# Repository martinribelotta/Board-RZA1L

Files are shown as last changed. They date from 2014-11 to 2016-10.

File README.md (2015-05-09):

RZ/A1L Board
============

Cortex-A9 board for Renesas RZ CPU using KiCAD

Hardware
--------

 - **CPU**: RZ/A1L 208LQFP
 - **RAM**: 32/64M sdram
 - **Flash**: 16/32M QSPI FLASH
 - **VGA**: 24bpp@\<TBD\>Hz
 - **USB**: 1 Host & 1 Dev
 - **GPIO**: 30 GPIO (+6 LED +2 Button) Muxed with:

Block Diagram
-------------

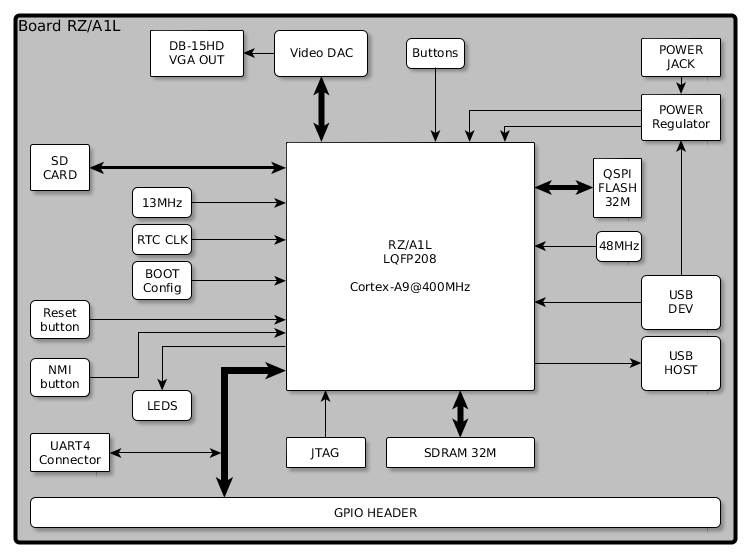
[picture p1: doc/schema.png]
Block Diagram


Schematic
---------

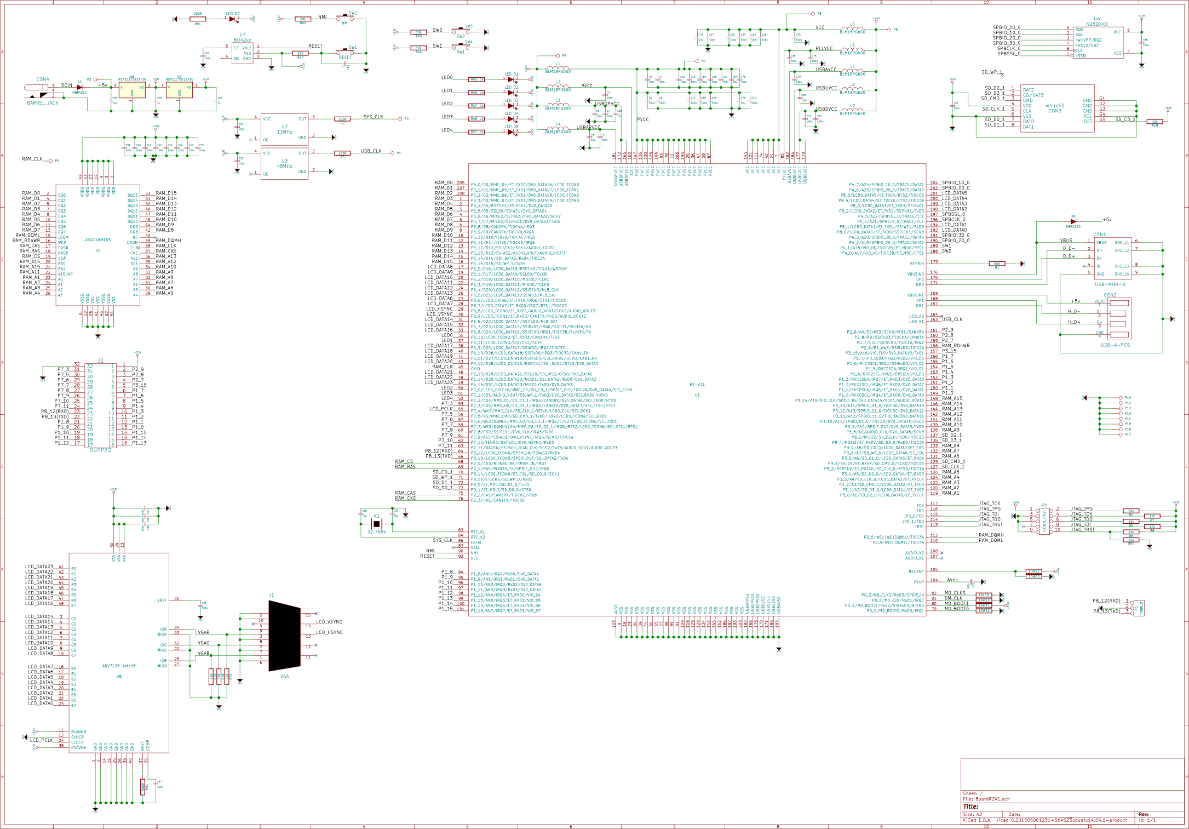
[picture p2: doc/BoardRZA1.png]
Schematic


Preview
-------

Top view

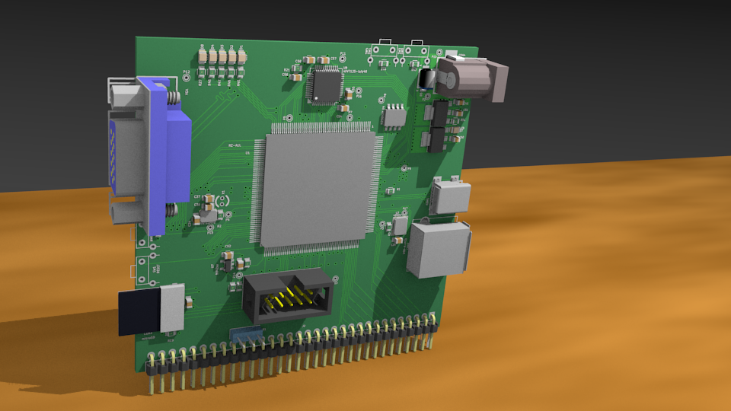
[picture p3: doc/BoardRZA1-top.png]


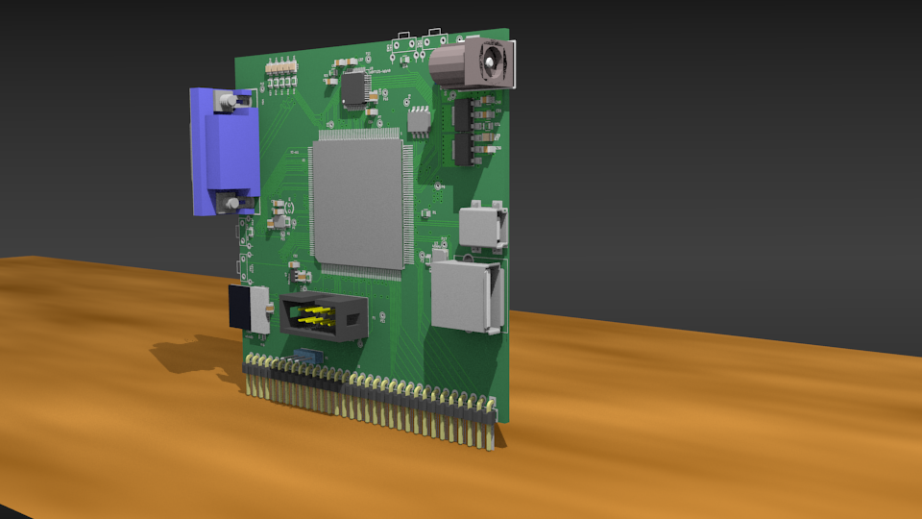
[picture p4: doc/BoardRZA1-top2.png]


Bottom view

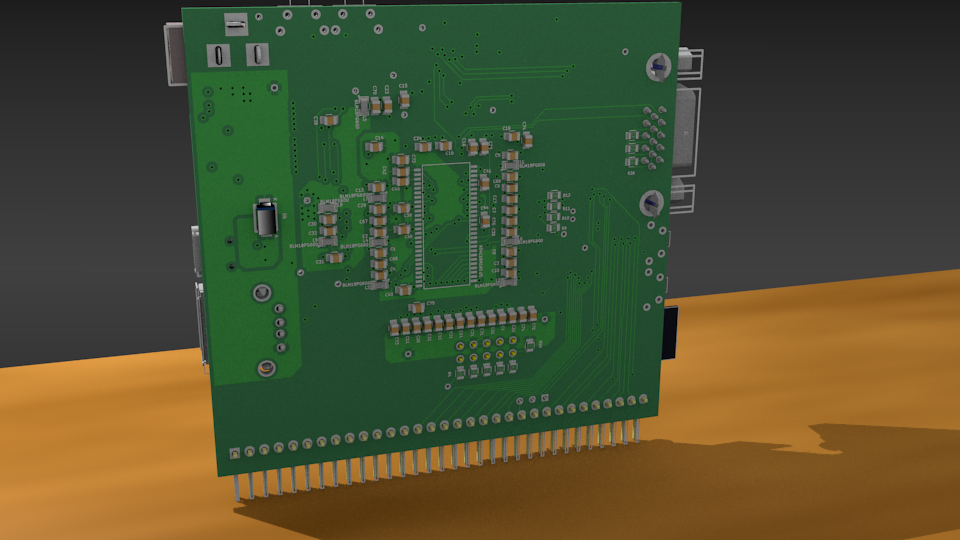
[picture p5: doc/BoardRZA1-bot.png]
Bottom


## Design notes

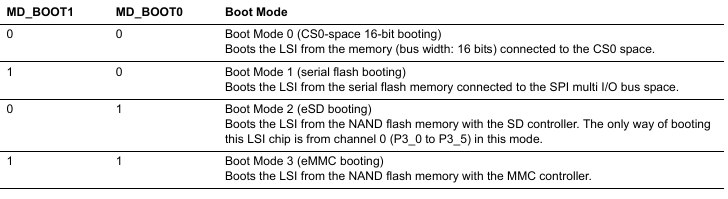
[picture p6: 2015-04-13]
doc/boot-modes-a1l.png

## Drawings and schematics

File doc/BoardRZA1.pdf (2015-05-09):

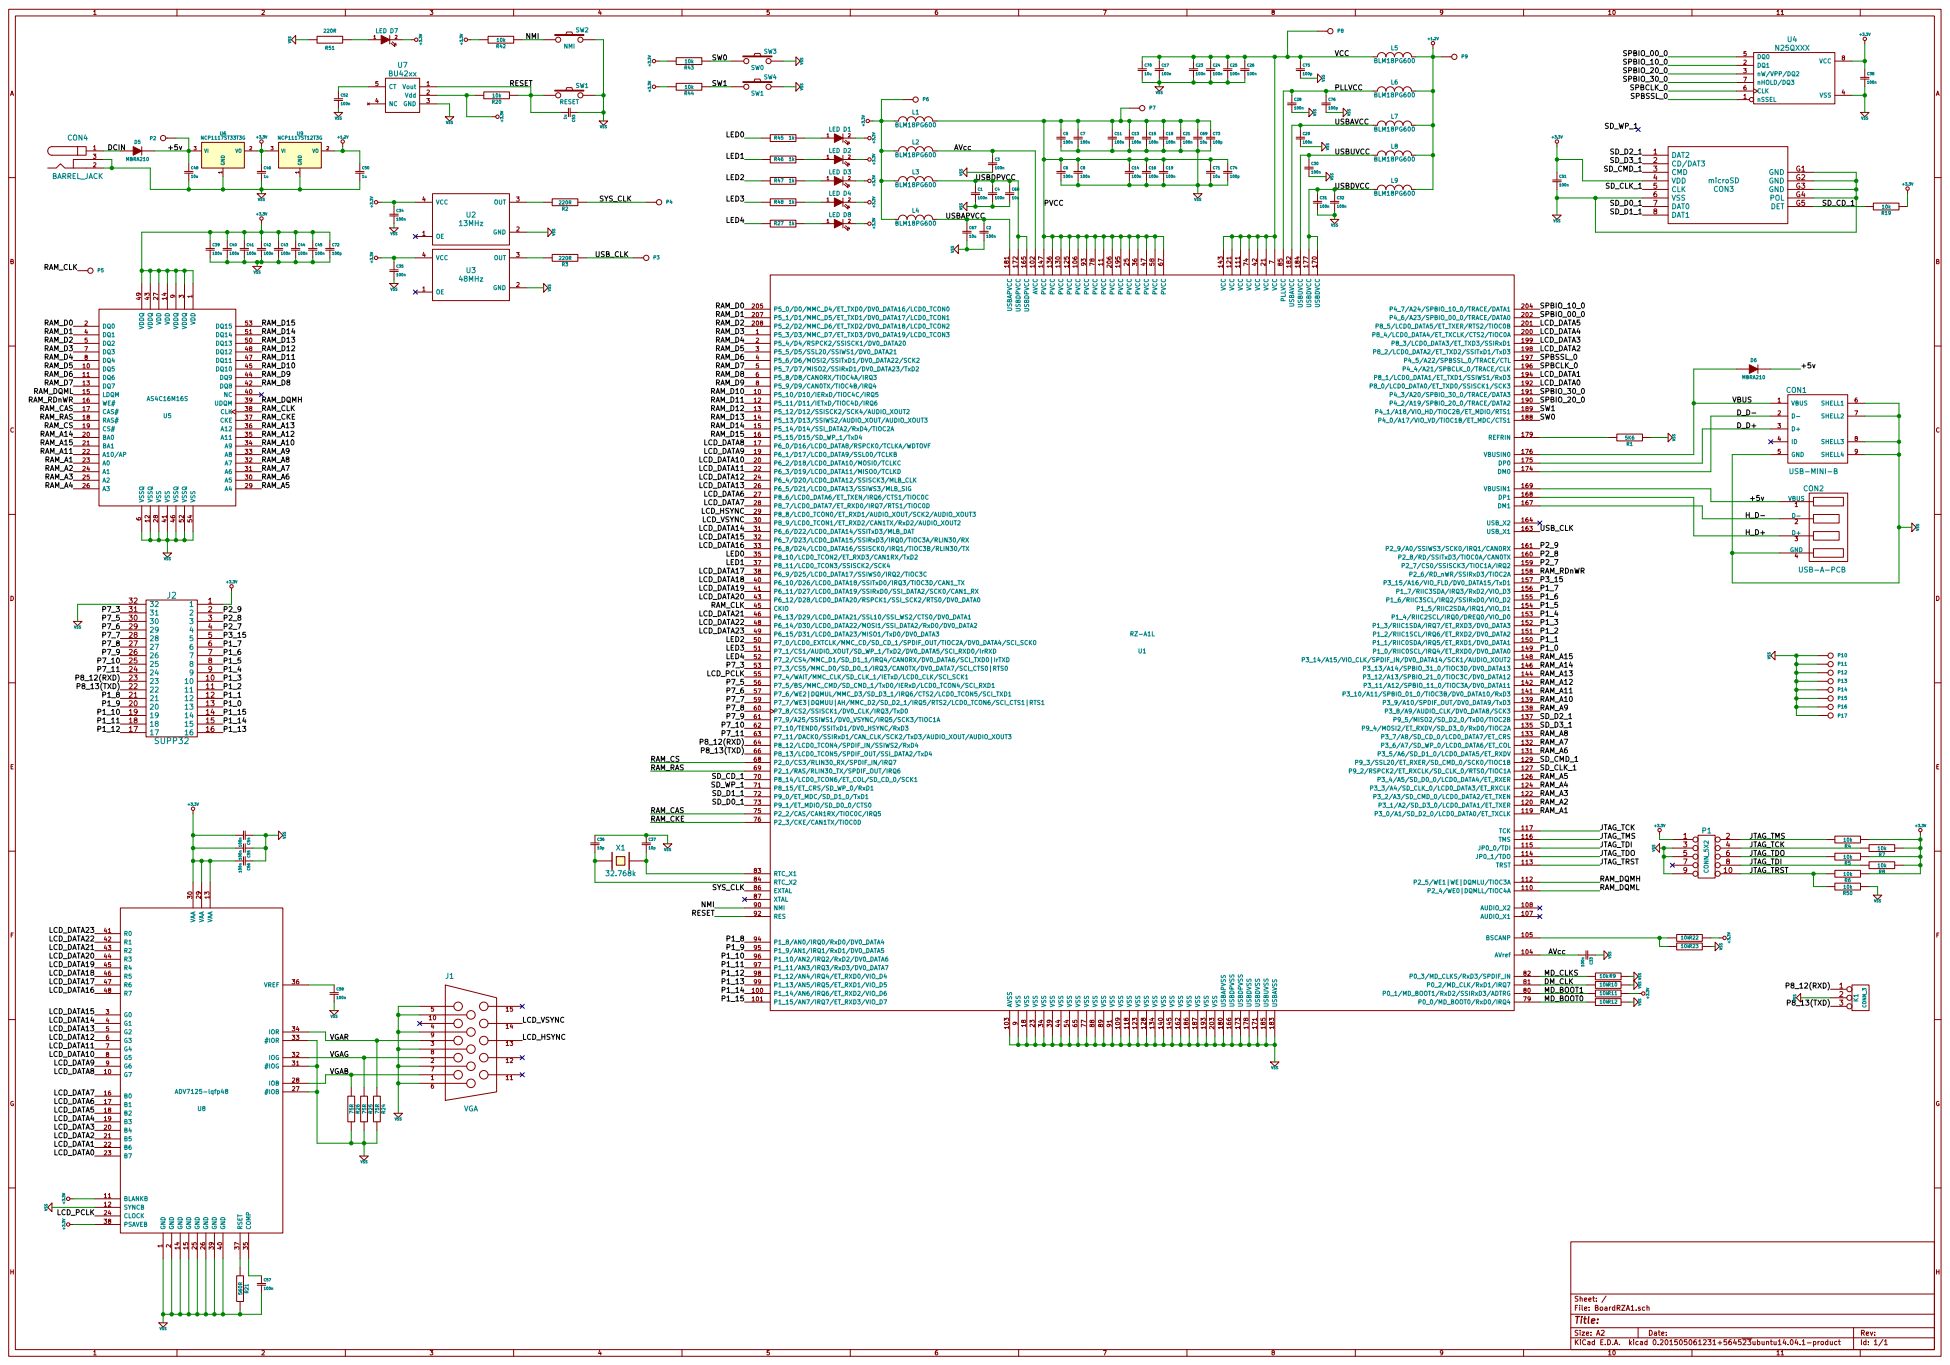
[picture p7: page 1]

9 DQ5 10 BA0 20 A5 30 NC 40 DQ13 50 DQ6 11 BA1 21 A6 31 VSS 41 DQ14 51 VSSQ 12 A10/AP 22 A7 32 DQ8 42 VSSQ 52 DQ7 13 A0 23 A8 33 VDDQ 43 DQ15 VDD 53 14 A1 24 A9 34 DQ9 44 VSS 54

Id: 1/1 Title: File: BoardRZA1.sch Sheet: /

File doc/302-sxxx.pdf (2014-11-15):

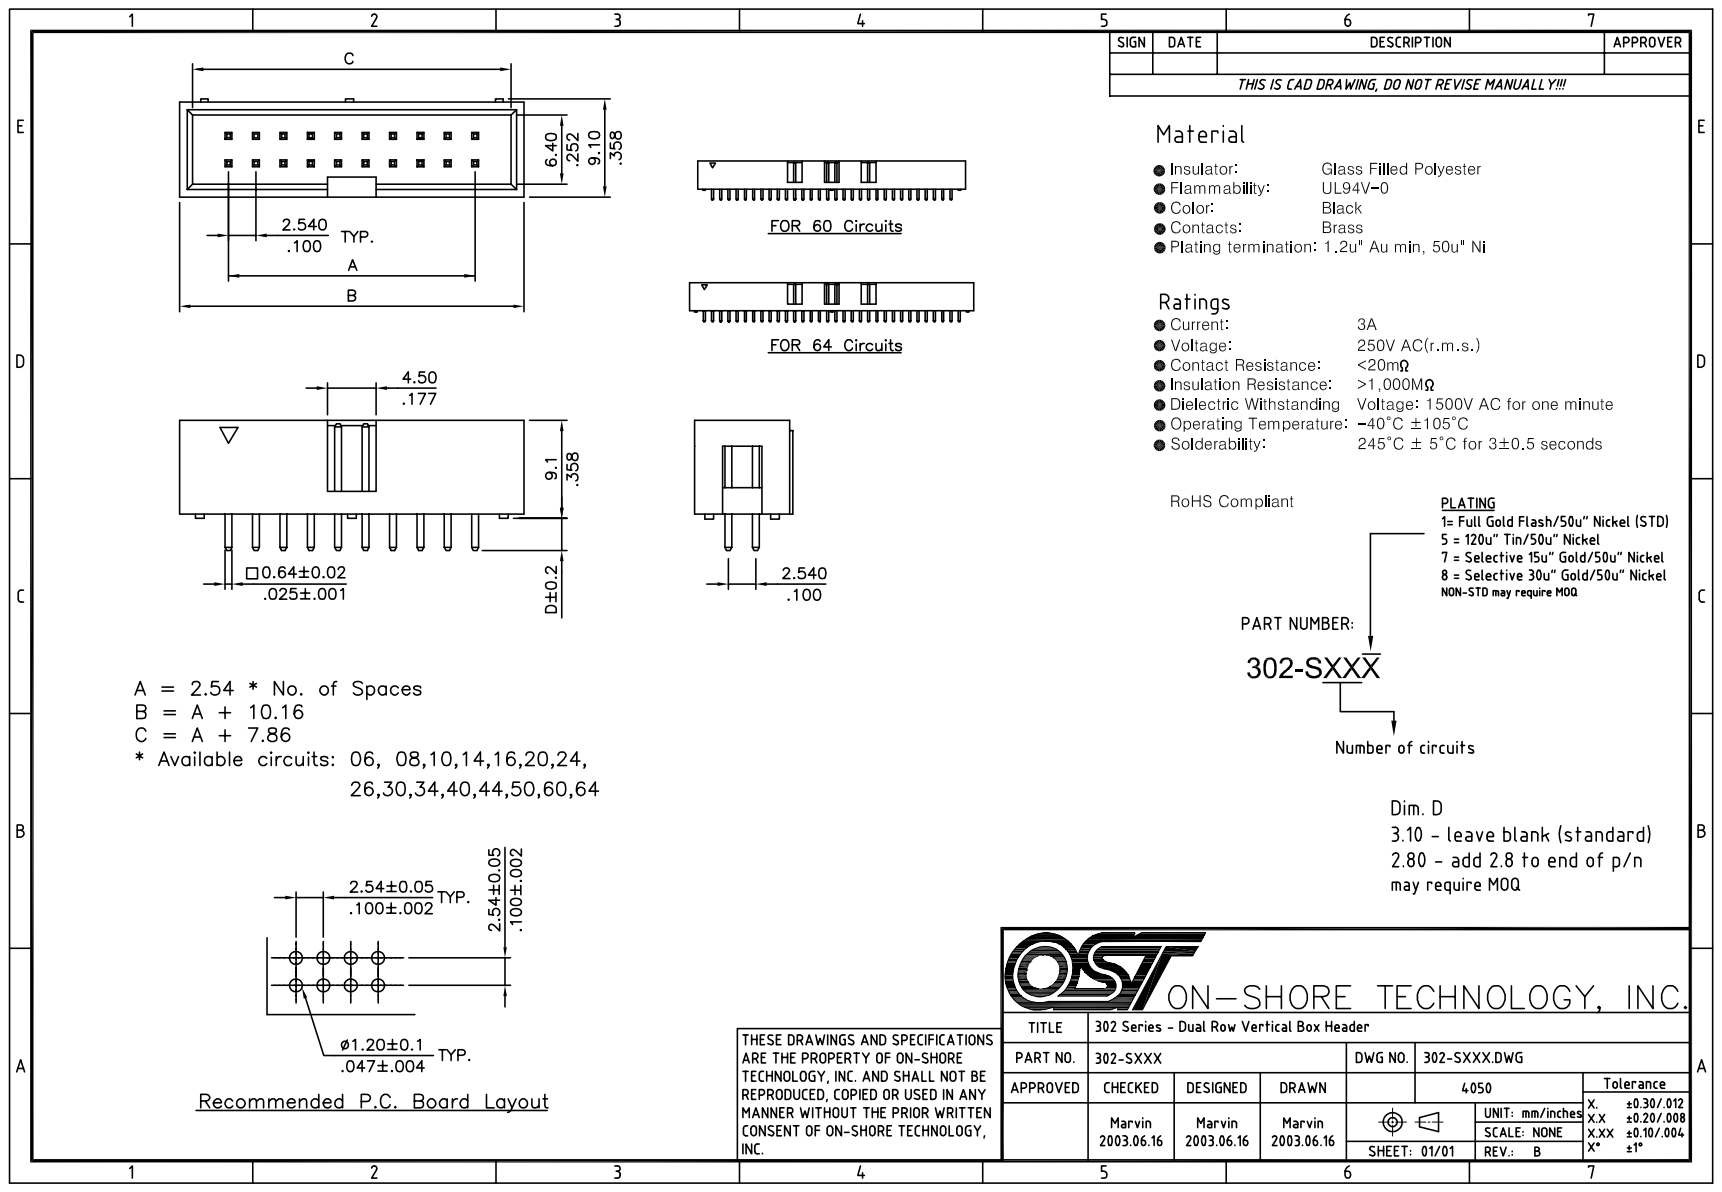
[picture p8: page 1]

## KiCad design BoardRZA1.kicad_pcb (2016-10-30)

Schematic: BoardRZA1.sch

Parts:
C1, C2, C3, C4, C5, C6, C7, C8, C11, C13, C14, C15, C16, C17, C18, C19, C21, C23, C24, C25, C26, C28, C29, C30, C31, C32, C33, C34, C35, C38, C39, C40, C41, C42, C43, C44, C45, C51, C52: 100n; C_0805
C36, C37: 10p; C_0805
C46, C50, C53: 1u; C_0805
C48, C67, C68, C69, C70, C71: 10u; C_0805
C72, C73, C74, C75, C76: 100p; C_0805
CON1: USB-MINI-B; USB_MINI_B
CON2: USB-A-PCB; USB_A_Vertical
CON3: microSD
D1, D2, D3, D4, D7, D8: LED; LED-0805
L1, L2, L3, L4, L5, L6, L7, L8, L9: BLM18PG600; SM0805
P1: CONN_02X04; Pin_Header_Straight_2x04
P2, P3, P4, P5, P6, P7, P8, P9, P10, P11, P12, P13, P14, P15, P16, P17: CONN_1; PINTST
P18, P19: CONN_01X40; Pin_Header_Straight_2x20
R1: 5K6; R_0805
R2, R3, R51: 220R; R_0805
R4, R5, R6, R7, R8, R9, R10, R11, R12, R19, R20, R22, R23, R42, R43, R44, R50: 10k; R_0805
R27, R45, R46, R47, R48: 1k; R_0805
SW1: RESET; RigthAnglePush
SW2: NMI; RigthAnglePush
SW3: SW0; RigthAnglePush
SW4: SW1; RigthAnglePush
U1: RZ-A1L; PQFP208
U2: 13MHz; OSC_2x2p5
U3: 48MHz; OSC_4PIN
U4: N25QXXX; SOP2-8
U5: AS4C16M16S; TSOP_II_54
U6: NCP1117ST33T3G; sot223
U7: BU42xx; SSOP-5
U9: NCP1117ST12T3G; sot223
X1: 32.768k; Crystal_Round_Vertical_3mm

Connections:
+1.2V: C50.1, L5.2, L6.2, L7.2, L8.2, L9.2, P9.1, U9.2 (VO)
+3.3V: C34.1, C35.1, C38.1, C39.1, C40.1, C41.1, C42.1, C43.1, C44.1, C45.1, C46.1, C51.1, C72.1, CON3.4 (VDD), D1.2 (K), D2.2 (K), D3.2 (K), D4.2 (K), D7.2 (K), D8.2 (K), L1.1, L2.1, L3.1, L4.1, P6.1, P18.3, P18.4, P18.37, P18.38, P19.3, P19.4, P19.37, P19.38, R4.1, R5.1, R6.1, R7.1, R8.1, R11.1, R19.1, R20.2, R22.1, R42.2, R43.2, R44.2, U2.4 (VCC), U3.4 (VCC), U4.8 (VCC), U5.1 (VDD), U5.3 (VDDQ), U5.9 (VDDQ), U5.14 (VDD), U5.27 (VDD), U5.43 (VDDQ), U5.49 (VDDQ), U6.2 (VO), U7.2 (Vdd), U9.3 (VI)
/+5v: C48.1, CON1.1 (VBUS), CON2.1 (VBUS), P2.1, U1.169 (VBUSIN1), U1.176 (VBUSIN0), U6.3 (VI)
/AVcc: C3.1, C33.2, L2.2, U1.102 (AVCC), U1.104 (AVref)
/DM_CLK: R10.2, U1.81 (P0_2/MD_CLK/RxD1/IRQ7)
/D_D+: CON1.3 (D+), U1.175 (DP0)
/D_D-: CON1.2 (D-), U1.174 (DM0)
/H_D+: CON2.3 (D+), U1.168 (DP1)
/H_D-: CON2.2 (D-), U1.167 (DM1)
/JTAG_TCK: P1.2, R7.2, U1.117 (TCK)
/JTAG_TDI: P1.6, R8.2, U1.115 (JP0_0/TDI)
/JTAG_TDO: P1.4, R5.2, U1.114 (JP0_1/TDO)
/JTAG_TMS: P1.1, R4.2, U1.116 (TMS)
/JTAG_TRST: P1.8, R6.2, R50.2, U1.113 (TRST)
/LCD_DATA0: P18.19, U1.192 (P8_0/LCD0_DATA0/ET_TXD0/SSISCK1/SCK3)
/LCD_DATA1: P18.20, U1.194 (P8_1/LCD0_DATA1/ET_TXD1/SSIWS1/RxD3)
/LCD_DATA2: P18.21, U1.198 (P8_2/LCD0_DATA2/ET_TXD2/SSITxD1/TxD3)
/LCD_DATA3: P18.22, U1.199 (P8_3/LCD0_DATA3/ET_TXD3/SSIRxD1)
/LCD_DATA4: P18.23, U1.200 (P8_4/LCD0_DATA4/ET_TXCLK/CTS2/TIOC0A)
/LCD_DATA5: P18.24, U1.201 (P8_5/LCD0_DATA5/ET_TXER/RTS2/TIOC0B)
/LCD_DATA6: P18.31, U1.27 (P8_6/LCD0_DATA6/ET_TXEN/IRQ6/CTS1/TIOC0C)
/LCD_DATA7: P18.32, U1.28 (P8_7/LCD0_DATA7/ET_RXD0/IRQ7/RTS1/TIOC0D)
/LCD_DATA8: P18.25, U1.17 (P6_0/D16/LCD0_DATA8/RSPCK0/TCLKA/WDTOVF)
/LCD_DATA9: P18.26, U1.19 (P6_1/D17/LCD0_DATA9/SSL00/TCLKB)
/LCD_DATA10: P18.27, U1.20 (P6_2/D18/LCD0_DATA10/MOSI0/TCLKC)
/LCD_DATA11: P18.28, U1.22 (P6_3/D19/LCD0_DATA11/MISO0/TCLKD)
/LCD_DATA12: P18.29, U1.24 (P6_4/D20/LCD0_DATA12/SSISCK3/MLB_CLK)
/LCD_DATA13: P18.30, U1.26 (P6_5/D21/LCD0_DATA13/SSIWS3/MLB_SIG)
/LCD_DATA14: P18.35, U1.31 (P6_6/D22/LCD0_DATA14/SSITxD3/MLB_DAT)
/LCD_DATA15: P18.36, U1.32 (P6_7/D23/LCD0_DATA15/SSIRxD3/IRQ0/TIOC3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)
/LCD_DATA16: P19.5, U1.33 (P6_8/D24/LCD0_DATA16/SSISCK0/IRQ1/TIOC3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)
/LCD_DATA17: P19.8, U1.38 (P6_9/D25/LCD0_DATA17/SSIWS0/IRQ2/TIOC3C)
/LCD_DATA18: P19.9, U1.40 (P6_10/D26/LCD0_DATA18/SSITxD0/IRQ3/TIOC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)
/LCD_DATA19: P19.10, U1.41 (P6_11/D27/LCD0_DATA19/SSIRxD0/SSI_DATA2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)
/LCD_DATA20: P19.11, U1.43 (P6_12/D28/LCD0_DATA20/RSPCK1/SSI_SCK2/R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)
/LCD_DATA21: P19.12, U1.46 (P6_13/D29/LCD0_DATA21/SSL10/SSI_WS2/CTS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)
/LCD_DATA22: P19.13, U1.48 (P6_14/D30/LCD0_DATA22/MOSI1/SSI_DATA2/R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)
/LCD_DATA23: P19.14, U1.49 (P6_15/D31/LCD0_DATA23/MISO1/TxD0/DV0_DA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)
/LCD_HSYNC: P18.33, U1.29 (P8_8/LCD0_TCON0/ET_RXD1/AUDIO_XOUT/SCK2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)
/LCD_PCLK: P19.19, U1.55 (P7_4/WAIT/MMC_CLK/SD_CLK_1/IETxD/LCD0_C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)
/LCD_VSYNC: P18.34, U1.30 (P8_9/LCD0_TCON1/ET_RXD2/CAN1TX/RxD2/AUD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)
/LED0: P19.7, R45.1, U1.35 (P8_10/LCD0_TCON2/ET_RXD3/CAN1RX/TxD2)
/LED1: P19.6, R46.1, U1.37 (P8_11/LCD0_TCON3/SSISCK2/SCK4)
/LED2: P19.15, R47.1, U1.50 (P7_0/LCD0_EXTCLK/MMC_CD/SD_CD_1/SPDIF_O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)
/LED3: P19.16, R48.1, U1.51 (P7_1/CS1/AUDIO_XOUT/SD_WP_1/TxD2/DV0_DA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)
/LED4: P19.17, R27.1, U1.52 (P7_2/CS4/MMC_D1/SD_D1_1/IRQ4/CAN0RX/DV0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)
/MD_BOOT0: R12.2, U1.79 (P0_0/MD_BOOT0/RxD0/IRQ4)
/MD_BOOT1: R11.2, U1.80 (P0_1/MD_BOOT1/RxD2/SSIRxD3/ADTRG)
/MD_CLKS: R9.2, U1.82 (P0_3/MD_CLKS/RxD3/SPDIF_IN)
/NMI: P19.27, R42.1, SW2.1, U1.90 (NMI)
/P1_0: P18.5, U1.149 (P1_0/RIIC0SCL/IRQ4/ET_RXD0/DV0_DATA0)
/P1_1: P18.6, U1.150 (P1_1/RIIC0SDA/IRQ5/ET_RXD1/DV0_DATA1)
/P1_2: P18.7, U1.151 (P1_2/RIIC1SCL/IRQ6/ET_RXD2/DV0_DATA2)
/P1_3: P18.8, U1.152 (P1_3/RIIC1SDA/IRQ7/ET_RXD3/DV0_DATA3)
/P1_4: P18.9, U1.153 (P1_4/RIIC2SCL/IRQ0/DREQ0/VIO_D0)
/P1_5: P18.10, U1.154 (P1_5/RIIC2SDA/IRQ1/VIO_D1)
/P1_6: P18.11, U1.155 (P1_6/RIIC3SCL/IRQ2/SSIRxD0/VIO_D2)
/P1_7: P18.12, U1.156 (P1_7/RIIC3SDA/IRQ3/RxD2/VIO_D3)
/P1_8: P19.29, U1.94 (P1_8/AN0/IRQ0/RxD0/DV0_DATA4)
/P1_9: P19.30, U1.95 (P1_9/AN1/IRQ1/RxD1/DV0_DATA5)
/P1_10: P19.31, U1.96 (P1_10/AN2/IRQ2/RxD2/DV0_DATA6)
/P1_11: P19.32, U1.97 (P1_11/AN3/IRQ3/RxD3/DV0_DATA7)
/P1_12: P19.33, U1.98 (P1_12/AN4/IRQ4/ET_RXD0/VIO_D4)
/P1_13: P19.34, U1.99 (P1_13/AN5/IRQ5/ET_RXD1/VIO_D5)
/P1_14: P19.35, U1.100 (P1_14/AN6/IRQ6/ET_RXD2/VIO_D6)
/P1_15: P19.36, U1.101 (P1_15/AN7/IRQ7/ET_RXD3/VIO_D7)
/P2_7: P18.14, U1.159 (P2_7/CS0/SSISCK3/TIOC1A/IRQ2)
/P2_8: P18.15, U1.160 (P2_8/RD/SSITxD3/TIOC0A/CAN0TX)
/P2_9: P18.16, U1.161 (P2_9/A0/SSIWS3/SCK0/IRQ1/CAN0RX)
/P3_15: P18.13, U1.157 (P3_15/A16/VIO_FLD/DV0_DATA15/TxD1)
/P7_3: P19.18, U1.53 (P7_3/CS5/MMC_D0/SD_D0_1/IRQ3/CAN0TX/DV0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)
/P7_5: P19.20, U1.56 (P7_5/BS/MMC_CMD/SD_CMD_1/TxD0/IERxD/LCD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)
/P7_6: P19.21, U1.57 (P7_6/WE2|DQMUL/MMC_D3/SD_D3_1/IRQ6/CTS2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)
/P7_7: P19.22, U1.59 (P7_7/WE3|DQMUU|AH/MMC_D2/SD_D2_1/IRQ5/R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)
/P7_8: P19.23, U1.60 (P7_8/CS2/SSISCK1/DV0_CLK/IRQ3/TxD0)
/P7_9: P19.24, U1.61 (P7_9/A25/SSIWS1/DV0_VSYNC/IRQ5/SCK3/TIO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)
/P7_10: P19.25, U1.62 (P7_10/TEND0/SSITxD1/DV0_HSYNC/RxD3)
/P7_11: P19.26, U1.63 (P7_11/DACK0/SSIRxD1/CAN_CLK/SCK2/TxD3/A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)
/P8_12(RXD): P1.3, U1.64 (P8_12/LCD0_TCON4/SPDIF_IN/SSIWS2/RxD4)
/P8_13(TXD): P1.5, U1.66 (P8_13/LCD0_TCON5/SPDIF_OUT/SSI_DATA2/Tx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)
/PLLVCC: C28.1, C76.1, L6.1, U1.85 (PLLVCC)
/PVCC: C5.1, C6.1, C7.1, C8.1, C11.1, C13.1, C14.1, C15.1, C16.1, C18.1, C19.1, C21.1, C69.1, C71.1, C73.1, C74.1, L1.2, P7.1, U1.11 (PVCC), U1.25 (PVCC), U1.36 (PVCC), U1.47 (PVCC), U1.58 (PVCC), U1.67 (PVCC), U1.78 (PVCC), U1.93 (PVCC), U1.106 (PVCC), U1.125 (PVCC), U1.130 (PVCC), U1.136 (PVCC), U1.147 (PVCC), U1.195 (PVCC), U1.206 (PVCC); also elsewhere on the board
/RAM_A1: U1.119 (P3_0/A1/SD_D2_0/LCD0_DATA0/ET_TXCLK), U5.23 (A0)
/RAM_A2: U1.120 (P3_1/A2/SD_D3_0/LCD0_DATA1/ET_TXER), U5.24 (A1)
/RAM_A3: U1.122 (P3_2/A3/SD_CMD_0/LCD0_DATA2/ET_TXEN), U5.25 (A2)
/RAM_A4: U1.124 (P3_3/A4/SD_CLK_0/LCD0_DATA3/ET_RXCLK), U5.26 (A3)
/RAM_A5: U1.126 (P3_4/A5/SD_D0_0/LCD0_DATA4/ET_RXER), U5.29 (A4)
/RAM_A6: U1.131 (P3_5/A6/SD_D1_0/LCD0_DATA5/ET_RXDV), U5.30 (A5)
/RAM_A7: U1.132 (P3_6/A7/SD_WP_0/LCD0_DATA6/ET_COL), U5.31 (A6)
/RAM_A8: U1.133 (P3_7/A8/SD_CD_0/LCD0_DATA7/ET_CRS), U5.32 (A7)
/RAM_A9: U1.138 (P3_8/A9/AUDIO_CLK/DV0_DATA8/SCK3), U5.33 (A8)
/RAM_A10: U1.139 (P3_9/A10/SPDIF_OUT/DV0_DATA9/TxD3), U5.34 (A9)
/RAM_A11: U1.141 (P3_10/A11/SPBIO_01_0/TIOC3B/DV0_DATA10/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), U5.22 (A10/AP)
/RAM_A12: U1.142 (P3_11/A12/SPBIO_11_0/TIOC3A/DV0_DATA11), U5.35 (A11)
/RAM_A13: U1.144 (P3_12/A13/SPBIO_21_0/TIOC3C/DV0_DATA12), U5.36 (A12)
/RAM_A14: U1.146 (P3_13/A14/SPBIO_31_0/TIOC3D/DV0_DATA13), U5.20 (BA0)
/RAM_A15: U1.148 (P3_14/A15/VIO_CLK/SPDIF_IN/DV0_DATA14/S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), U5.21 (BA1)
/RAM_CAS: U1.75 (P2_2/CAS/CAN1RX/TIOC0C/IRQ5), U5.17 (CAS#)
/RAM_CKE: U1.76 (P2_3/CKE/CAN1TX/TIOC0D), U5.37 (CKE)
/RAM_CLK: P5.1, U1.45 (CKIO), U5.38 (CLK)
/RAM_CS: U1.68 (P2_0/CS3/RLIN30_RX/SPDIF_IN/IRQ7), U5.19 (CS#)
/RAM_D0: U1.205 (P5_0/D0/MMC_D4/ET_TXD0/DV0_DATA16/LCD0_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), U5.2 (DQ0)
/RAM_D1: U1.207 (P5_1/D1/MMC_D5/ET_TXD1/DV0_DATA17/LCD0_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), U5.4 (DQ1)
/RAM_D2: U1.208 (P5_2/D2/MMC_D6/ET_TXD2/DV0_DATA18/LCD0_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), U5.5 (DQ2)
/RAM_D3: U1.1 (P5_3/D3/MMC_D7/ET_TXD3/DV0_DATA19/LCD0_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), U5.7 (DQ3)
/RAM_D4: U1.2 (P5_4/D4/RSPCK2/SSISCK1/DV0_DATA20), U5.8 (DQ4)
/RAM_D5: U1.3 (P5_5/D5/SSL20/SSIWS1/DV0_DATA21), U5.10 (DQ5)
/RAM_D6: U1.4 (P5_6/D6/MOSI2/SSITxD1/DV0_DATA22/SCK2), U5.11 (DQ6)
/RAM_D7: U1.5 (P5_7/D7/MISO2/SSIRxD1/DV0_DATA23/TxD2), U5.13 (DQ7)
/RAM_D8: U1.6 (P5_8/D8/CAN0RX/TIOC4A/IRQ3), U5.42 (DQ8)
/RAM_D9: U1.8 (P5_9/D9/CAN0TX/TIOC4B/IRQ4), U5.44 (DQ9)
/RAM_D10: U1.10 (P5_10/D10/IERxD/TIOC4C/IRQ5), U5.45 (DQ10)
/RAM_D11: U1.12 (P5_11/D11/IETxD/TIOC4D/IRQ6), U5.47 (DQ11)
/RAM_D12: U1.13 (P5_12/D12/SSISCK2/SCK4/AUDIO_XOUT2), U5.48 (DQ12)
/RAM_D13: U1.14 (P5_13/D13/SSIWS2/AUDIO_XOUT/AUDIO_XOUT3), U5.50 (DQ13)
/RAM_D14: U1.15 (P5_14/D14/SSI_DATA2/RxD4/TIOC2A), U5.51 (DQ14)
/RAM_D15: U1.16 (P5_15/D15/SD_WP_1/TxD4), U5.53 (DQ15)
/RAM_DQMH: U1.112 (P2_5/WE1|WE|DQMLU/TIOC3A), U5.39 (UDQM)
/RAM_DQML: U1.110 (P2_4/WE0|DQMLL/TIOC4A), U5.15 (LDQM)
/RAM_RAS: U1.69 (P2_1/RAS/RLIN30_TX/SPDIF_OUT/IRQ6), U5.18 (RAS#)
/RAM_RDnWR: U1.158 (P2_6/RD_nWR/SSIRxD3/TIOC2A), U5.16 (WE#)
/RESET: C53.2, P19.28, R20.1, SW1.1, U1.92 (RES), U7.1 (Vout)
/SD_CD_1: CON3.G5 (DET), R19.2, U1.70 (P8_14/LCD0_TCON6/ET_COL/SD_CD_0/SCK1)
/SD_CLK_1: CON3.5 (CLK), U1.127 (P9_2/RSPCK2/ET_RXCLK/SD_CLK_0/RTS0/TIOC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)
/SD_CMD_1: CON3.3 (CMD), U1.129 (P9_3/SSL20/ET_RXER/SD_CMD_0/SCK0/TIOC1B)
/SD_D0_1: CON3.7 (DAT0), U1.73 (P9_1/ET_MDIO/SD_D0_0/CTS0)
/SD_D1_1: CON3.8 (DAT1), U1.72 (P9_0/ET_MDC/SD_D1_0/TxD1)
/SD_D2_1: CON3.1 (DAT2), U1.137 (P9_5/MISO2/SD_D2_0/TxD0/TIOC2B)
/SD_D3_1: CON3.2 (CD/DAT3), U1.135 (P9_4/MOSI2/ET_RXDV/SD_D3_0/RxD0/TIOC2A)
/SPBCLK_0: U1.196 (P4_4/A21/SPBCLK_0/TRACE/CLK), U4.6 (CLK)
/SPBIO_00_0: U1.202 (P4_6/A23/SPBIO_00_0/TRACE/DATA0), U4.5 (DQ0)
/SPBIO_10_0: U1.204 (P4_7/A24/SPBIO_10_0/TRACE/DATA1), U4.2 (DQ1)
/SPBIO_20_0: U1.190 (P4_2/A19/SPBIO_20_0/TRACE/DATA2), U4.3 (nW/VPP/DQ2)
/SPBIO_30_0: U1.191 (P4_3/A20/SPBIO_30_0/TRACE/DATA3), U4.7 (nHOLD/DQ3)
/SPBSSL_0: U1.197 (P4_5/A22/SPBSSL_0/TRACE/CTL), U4.1 (nSSEL)
/SW0: P18.17, R43.1, SW3.1, U1.188 (P4_0/A17/VIO_VD/TIOC1B/ET_MDC/CTS1)
/SW1: P18.18, R44.1, SW4.1, U1.189 (P4_1/A18/VIO_HD/TIOC2B/ET_MDIO/RTS1)
/SYS_CLK: P4.1, R2.1, U1.86 (EXTAL)
/USBAPVCC: C2.1, C67.1, L4.2, U1.181 (USBAPVCC)
/USBAVCC: C29.1, L7.1, U1.182 (USBAVCC)
/USBDPVCC: C1.1, C4.1, C68.1, L3.2, U1.165 (USBDPVCC), U1.172 (USBDPVCC)
/USBDVCC: C31.1, C32.1, L9.1, U1.170 (USBDVCC), U1.177 (USBDVCC)
/USBUVCC: C30.1, L8.1, U1.184 (USBUVCC)
/USB_CLK: P3.1, R3.1, U1.163 (USB_X1)
/VCC: C17.1, C23.1, C24.1, C25.1, C26.1, C70.1, C75.1, L5.1, P8.1, U1.7 (VCC), U1.21 (VCC), U1.42 (VCC), U1.74 (VCC), U1.111 (VCC), U1.121 (VCC), U1.143 (VCC); also elsewhere on the board
unnamed: C36.2, U1.84 (RTC_X2), X1.1
unnamed: C37.2, U1.83 (RTC_X1), X1.2
unnamed: C52.1, U7.5 (CT)
unnamed: D1.1 (A), R45.2
unnamed: D2.1 (A), R46.2
unnamed: D3.1 (A), R47.2
unnamed: D4.1 (A), R48.2
unnamed: D7.1 (A), R51.2
unnamed: D8.1 (A), R27.2
unnamed: R1.2, U1.179 (REFRIN)
unnamed: R2.2, U2.3 (OUT)
unnamed: R3.2, U3.3 (OUT)
unnamed: R22.2, R23.2, U1.105 (BSCANP)
VSS: C1.2, C2.2, C3.2, C4.2, C5.2, C6.2, C7.2, C8.2, C11.2, C13.2, C14.2, C15.2, C16.2, C17.2, C18.2, C19.2, C21.2, C23.2, C24.2, C25.2, C26.2, C28.2, C29.2, C30.2, C31.2, C32.2, C33.1, C34.2, C35.2, C36.1, C37.1, C38.2, C39.2, C40.2, C41.2, C42.2, C43.2, C44.2, C45.2, C46.2, C48.2, C50.2, C51.2, C52.2, C53.1, C67.2, C68.2, C69.2, C70.2, C71.2, C72.2, C73.2, C74.2, C75.2, C76.2, CON1.5 (GND), CON1.6 (SHELL1), CON1.7 (SHELL2), CON1.8 (SHELL3), CON1.9 (SHELL4), CON2.4 (GND), CON3.6 (VSS), CON3.G1 (GND), CON3.G2 (GND), CON3.G3 (GND), CON3.G4 (POL), P1.7, P10.1, P11.1, P12.1, P13.1, P14.1, P15.1, P16.1, P17.1, P18.1, P18.2, P18.39, P18.40, P19.1, P19.2, P19.39, P19.40, R1.1, R9.1, R10.1, R12.1, R23.1, R50.1, R51.1, SW1.2, SW2.2, SW3.2, SW4.2, U1.9 (VSS), U1.18 (VSS), U1.23 (VSS), U1.34 (VSS), U1.39 (VSS), U1.44 (VSS), U1.54 (VSS), U1.65 (VSS), U1.77 (VSS), U1.88 (VSS), U1.89 (VSS), U1.91 (VSS), U1.103 (AVSS), U1.109 (VSS), U1.118 (VSS), U1.123 (VSS), U1.128 (VSS), U1.134 (VSS), U1.140 (VSS), U1.145 (VSS), U1.162 (VSS), U1.166 (USBDPVSS), U1.171 (USBDVSS), U1.173 (USBDPVSS), U1.178 (USBDVSS), U1.180 (USBAPVSS), U1.183 (USBAVSS), U1.185 (USBUVSS), U1.186 (VSS), U1.187 (VSS), U1.193 (VSS), U1.203 (VSS), U2.2 (GND), U3.2 (GND), U4.4 (VSS), U5.6 (VSSQ), U5.12 (VSSQ), U5.28 (VSS), U5.41 (VSS), U5.46 (VSSQ), U5.52 (VSSQ), U5.54 (VSS), U6.1 (GND), U7.3 (GND), U9.1 (GND); also elsewhere on the board

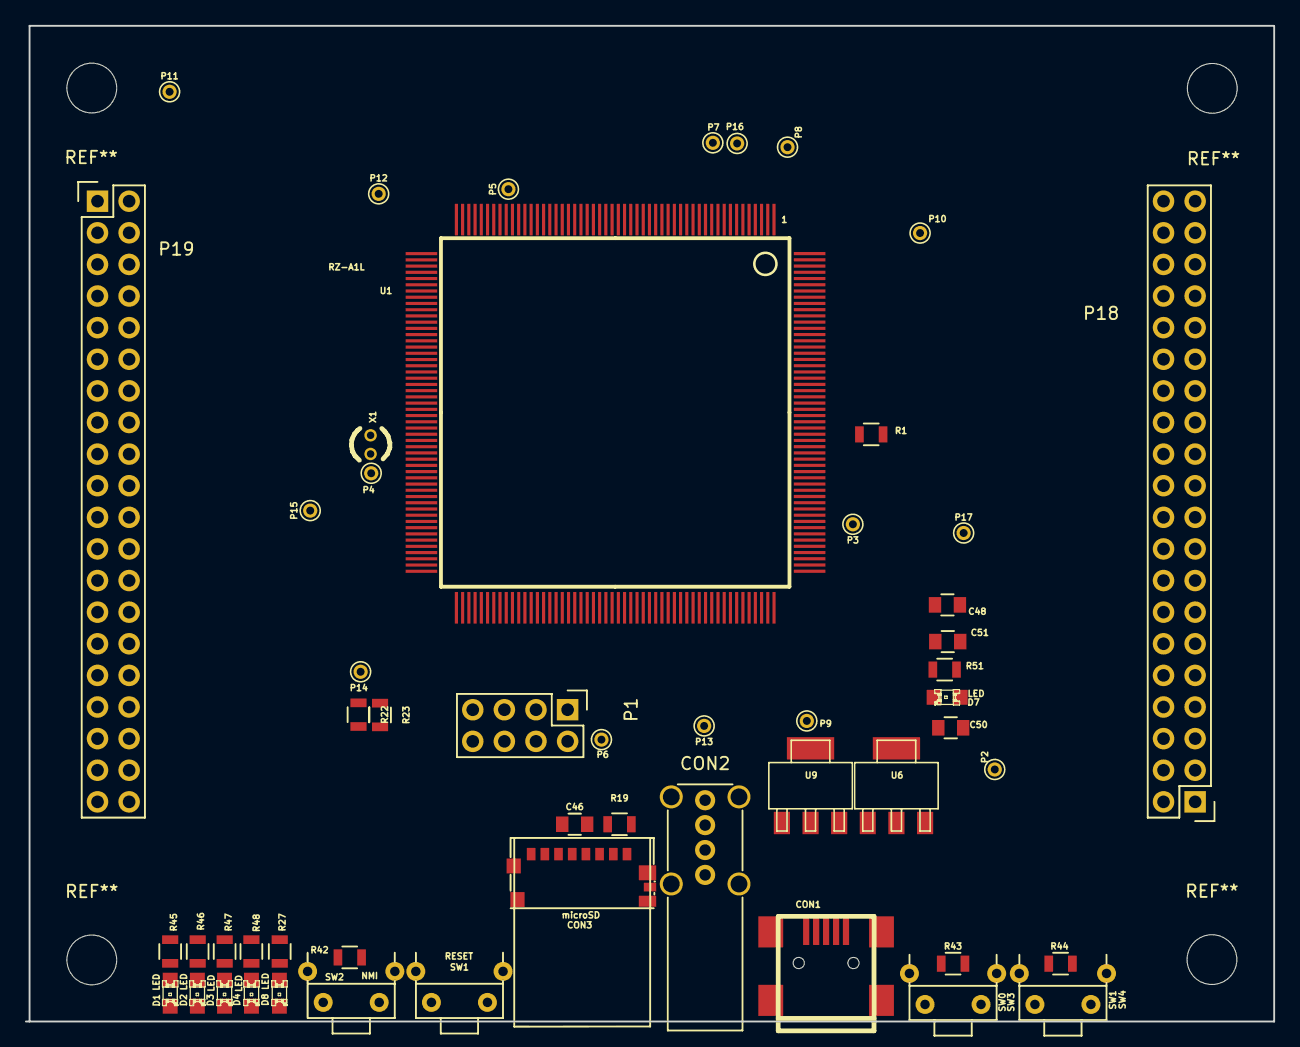
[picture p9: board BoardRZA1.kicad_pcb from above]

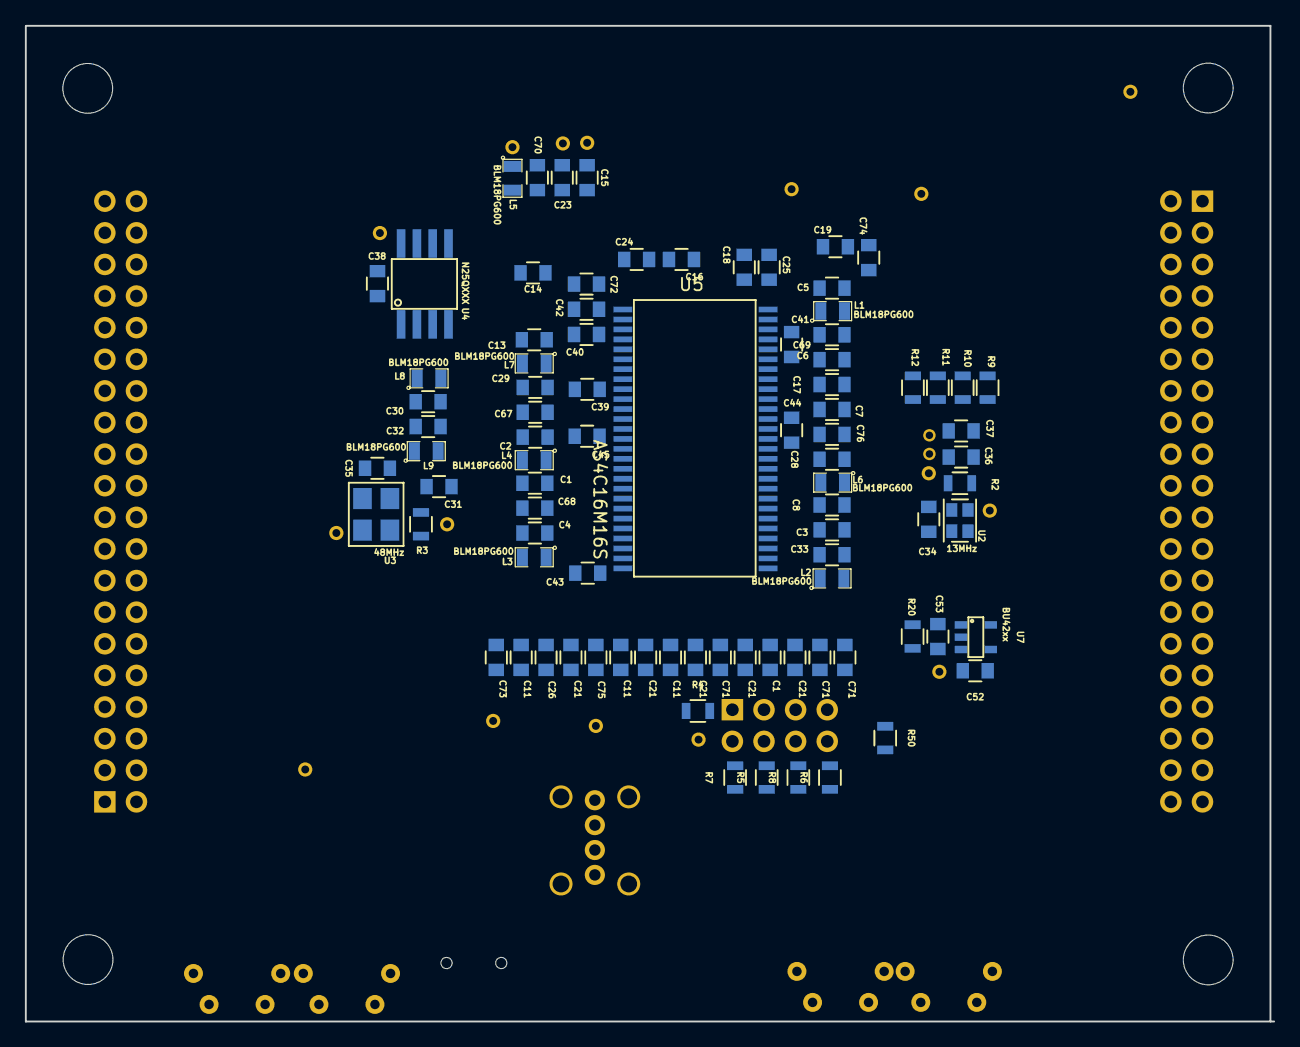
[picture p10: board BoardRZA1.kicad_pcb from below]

Board: 4 copper layers, 100.3 x 80.0 mm, 140 parts (87 on the bottom side), 159 nets, no tracks yet.

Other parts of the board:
C1#2, C11#2, C11#3, C21#2, C21#3, C21#4, C21#5: 100n; C_0805
C71#2, C71#3: 100p; C_0805

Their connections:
/PVCC: C1#2.1, C11#2.1, C11#3.1, C21#2.1, C21#3.1, C71#2.1; also elsewhere on the board
/VCC: C21#4.1, C21#5.1, C71#3.1; also elsewhere on the board
VSS: C1#2.2, C11#2.2, C11#3.2, C21#2.2, C21#3.2, C21#4.2, C21#5.2, C71#2.2, C71#3.2; also elsewhere on the board

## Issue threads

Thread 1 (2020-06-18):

which software you use to draw Block Diagram

yueleilei, 2020-06-18:
I send mail to u. can not reach.

英文说明:SMTP error, RCPT TO: Host gmail.com(74.125.127.26) RCPT TO said 550-5.1.1 The email account that you tried to reach does not exist. Please try
550-5.1.1 double-checking the recipient's email address for typos or
550-5.1.1 unnecessary spaces. Learn more at
550 5.1.1  https://support.google.com/mail/?p=NoSuchUser w10si1657182otl.39 - gsmtp

mailto:martinribelott@gmail.com

martinribelotta, 2020-06-18:
Correct mailto: martinribelotta@gmail.com
My diagram software is draw.io

martinribelotta, 2020-06-18:
I fix my email address in github account

Closed 2020-06-18.

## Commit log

2014-11-09 Readme and some images from kicad render
2014-11-11 Ruteo de power. Reogranizado de la plaqueta y planos de masa
    [BoardRZA1.kicad_pcb, BoardRZA1.sch]
2014-11-11 Actualizado preview 3d
    [BoardRZA1.kicad_pcb]
2014-11-15 Add ETH Add reset system Correct clock footprint Finish main routing and power/gnd planes
    [BoardRZA1.kicad_pcb, BoardRZA1.sch]
2014-11-16 GPIO routed
    [BoardRZA1-t0.kicad_pcb, BoardRZA1-t1.kicad_pcb, BoardRZA1.kicad_pcb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]
2014-11-18 Leds&buttons rerout eth out
    [BoardRZA1.kicad_pcb, BoardRZA1.sch]
2014-11-18 Cambia XTAL 25MHz Phy por OSC 25MHz
    [BoardRZA1.kicad_pcb, BoardRZA1.sch]
2014-11-19 USB-B CON2 -> USB-A CON2
    [BoardRZA1.kicad_pcb, BoardRZA1.sch]
2014-11-20 Add power from mini usb-b Prettify 3D
    [BoardRZA1.kicad_pcb, BoardRZA1.sch]
2014-11-20 Logo & move some nets
    [BoardRZA1.kicad_pcb]
2014-11-21 PHY OSC to XI fixed. Move some refs. Optional pulldown on TRST
    [BoardRZA1.kicad_pcb, BoardRZA1.sch]
2014-11-22 Add 10uF decouple on pvcc, vcc & 3v3
    [BoardRZA1.kicad_pcb, BoardRZA1.sch]
2014-11-24 Add 100pF C over power rails (700MHz filters) ERC pass DRC pass
    [BoardRZA1.kicad_pcb, BoardRZA1.sch]
2014-11-27 Arrangue PCB
    [BoardRZA1.kicad_pcb]
2014-11-30 Correct U4 SOP2-8 package. Rearangue footprint libraries
    [BoardRZA1.kicad_pcb, BoardRZA1.sch]
2014-12-03 Add vias to decouple cap. over VSS.
    [BoardRZA1.kicad_pcb]
2014-12-04 Add testpoints
    [BoardRZA1.kicad_pcb, BoardRZA1.sch]
2014-12-06 Arrange Sylkscreen
    [BoardRZA1.kicad_pcb, BoardRZA1.sch]
2014-12-13 Rearrange sylkscreen over GPIO connector
    [BoardRZA1.kicad_pcb]
2014-12-17 Add serial connector over UART4. Add GPIO labels, update images
    [BoardRZA1.kicad_pcb, BoardRZA1.sch]
2014-12-28 Minor changes
    [BoardRZA1.kicad_pcb]
2014-12-28 Arrange inner power planes
    [BoardRZA1.kicad_pcb]
2014-12-28 Rework power planes (2)
    [BoardRZA1.kicad_pcb]
2015-01-12 Clean schematic libreary
    [BoardRZA1.kicad_pcb]
2015-01-31 Some minor changes to PCB
    [BoardRZA1.kicad_pcb]
2015-01-31 Add PDF schematic
2015-03-03 Added VGA out, remove eth
    [BoardRZA1.kicad_pcb, BoardRZA1.sch]
2015-03-03 Resize board, move VGA connector and R2R DAC
    [BoardRZA1.kicad_pcb, BoardRZA1.sch]
2015-03-05 Some minor routing changes to probe new kicad assisted route
    [BoardRZA1.kicad_pcb]
2015-03-08 Update diagrams and pictures (1)
    [BoardRZA1.kicad_pcb, BoardRZA1.sch]
2015-03-08 Actualized schematic
    [BoardRZA1.kicad_pcb, BoardRZA1.sch]
2015-03-20 Change R2R DAC for ADV7125 on LQFP48
    [BoardRZA1.kicad_pcb, BoardRZA1.sch]
2015-03-24 Minimal modifications
    [BoardRZA1.kicad_pcb]
2015-03-31 Schematic SVG to PNG. README.md github not support SVG
2015-04-13 Change SD_*_1 to SD_*_0 because LCD0_CLK is overlapped by SD_CLK_1
    [BoardRZA1.kicad_pcb, BoardRZA1.sch]
2015-04-17 Move VGA connector, MicroSD connector, reasign GPIO
    [BoardRZA1.kicad_pcb, BoardRZA1.sch]
2015-04-23 Documentation and 3d views
    [BoardRZA1-B_Cu.gbr, BoardRZA1-B_SilkS.gbr, BoardRZA1-F_Cu.gbr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]
2015-05-03 PCB minor modifications
    [BoardRZA1-B_Cu.gbr, BoardRZA1-B_SilkS.gbr, BoardRZA1-F_Cu.gbr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]
2015-05-06 Replace monlitic dual regulator by two XX1117-Y.Z
    [BoardRZA1.kicad_pcb, BoardRZA1.sch]
2015-05-07 New Routing
    [BoardRZA1.kicad_pcb, BoardRZA1.sch]
2015-05-09 Minor touch of board
    [BoardRZA1.kicad_pcb]
2015-05-09 Documentation, images and schematic updates
    [BoardRZA1-B_Cu.gbr, BoardRZA1-B_SilkS.gbr, BoardRZA1-F_Cu.gbr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]
2015-06-16 Update board minor changes
    [BoardRZA1.kicad_pcb]
2015-07-01 Gerber files in protel format
    [BoardRZA1-B_Cu.gbl, BoardRZA1-B_Mask.gbs, BoardRZA1-B_Paste.gbp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]
2015-12-03 Change SOP2-8 pad size
    [BoardRZA1.kicad_pcb]
2016-10-23 Fix TSSOP II 54 SDRAM footprint
    [BoardRZA1.kicad_pcb]
2016-10-24 Minor bugfix on PCB layout reimport
    [BoardRZA1.kicad_pcb]
2016-10-30 Rework on minimize board
    [BoardRZA1.kicad_pcb, BoardRZA1.sch]
